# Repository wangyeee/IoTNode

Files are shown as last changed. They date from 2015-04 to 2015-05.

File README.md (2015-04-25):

# IoTNode

My IoT implementation with STM32F0 and nRF24L01.

## Compile and run

1. Install [GNU Tools for ARM Embedded Processors](https://launchpad.net/gcc-arm-embedded). And execute `make` to compile the code.
2. For Linux and OS X, clone this [repo](https://github.com/texane/stlink), follow the instructions on that page and install st-util to your system.
3. Execute `make flash` to download the binray to a STM32F0 target via ST Link.

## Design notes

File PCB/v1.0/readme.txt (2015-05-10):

The first version of hardware, tested and working under normal circumstances. But it’s not carefully designed as I’m not a experienced hardware developer.

Reference documents:
AN4080: Getting started with STM32F0x1/x2/x8 hardware development.
RM0360: STM32F030x4/6/8/C and STM32F070x6/B advanced ARM-based 32-bit MCUs Reference manual.
STM32F072B Discovery board schematics.

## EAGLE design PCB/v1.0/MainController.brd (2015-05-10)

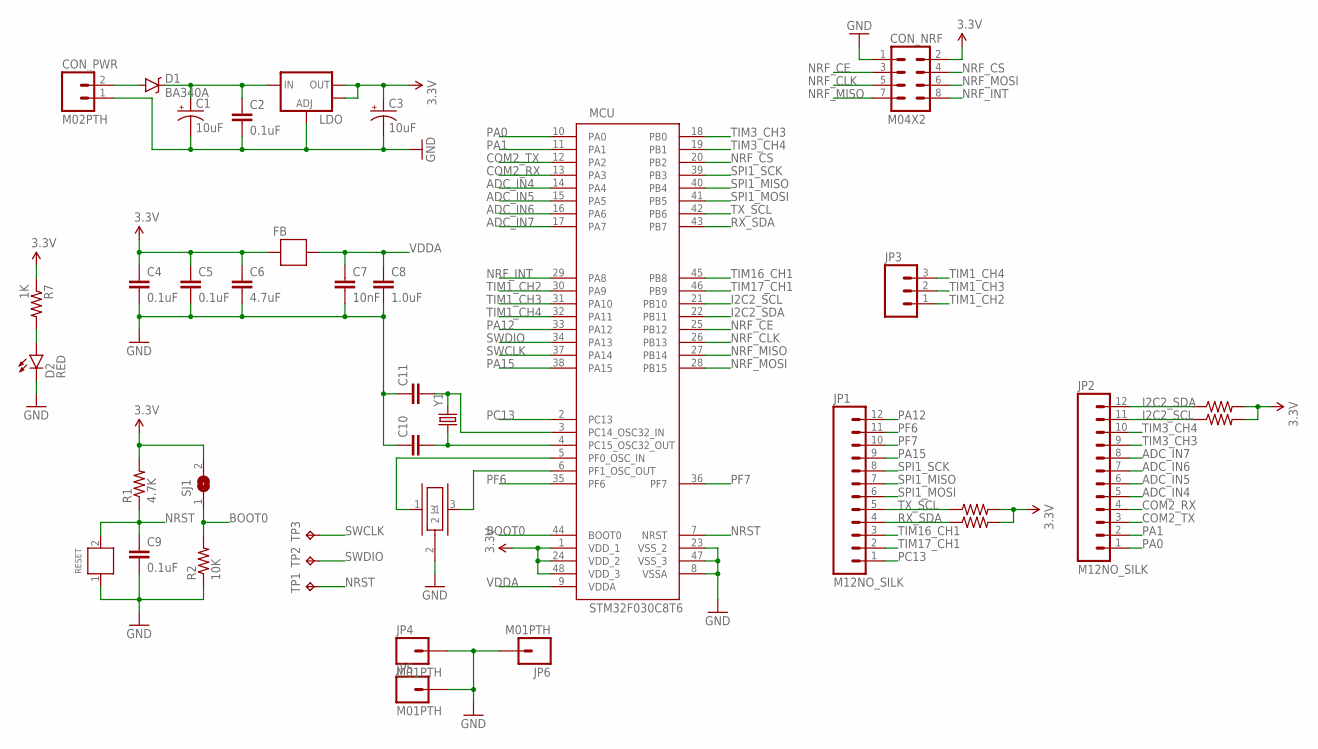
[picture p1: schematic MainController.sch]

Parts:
C1, C3: 10uF; EIA3216
C2, C4, C5, C9: 0.1uF; 0603-CAP
C6: 4.7uF; 0603-CAP
C7: 10nF; 0603-CAP
C8: 1.0uF; 0603-CAP
C10, C11: CAP0603-CAP; 0603-CAP
CON_NRF: M04X2; 2X4
CON_PWR: M02PTH; 1X02
D1: BA340A; SMA-DIODE
D2: RED; LED-0603
FB: FBFB0805; 0805W
JP1, JP2: M12NO_SILK; 1X12_NO_SILK
JP3: M031X03_NO_SILK; 1X03_NO_SILK
JP4, JP5, JP6: M01PTH; 1X01
LDO: V_REG_LM1117SOT223; SOT223
MCU: STM32F030C8T6; TQFP48
OSC: CSTCE8M00G52-R0; CSTCE_M_G
R1: 4.7K; 0603-RES
R2, R3, R4, R5, R6: 10K; 0603-RES
R7: 1K; 0603-RES
RESET: SWITCH_SMD; SWITCH3X6_SMD
SJ1: SJ
TP1, TP2, TP3: TPB1,27; B1,27
Y1: CRYSTALTC38H; TC38H

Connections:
3.3V: C3.A (+), C4.1, C5.1, C6.1, CON_NRF.2, FB.2, LDO.2 (OUT), LDO.4 (OUT), MCU.1 (VDD_1), MCU.24 (VDD_2), MCU.48 (VDD_3), R1.2, R3.2, R4.2, R5.2, R6.2, R7.1, SJ1.2
ADC_IN4: JP2.5, MCU.14 (PA4)
ADC_IN5: JP2.6, MCU.15 (PA5)
ADC_IN6: JP2.7, MCU.16 (PA6)
ADC_IN7: JP2.8, MCU.17 (PA7)
BOOT0: MCU.44 (BOOT0), R2.2, SJ1.1
COM2_RX: JP2.4, MCU.13 (PA3)
COM2_TX: JP2.3, MCU.12 (PA2)
GND: C1.C (-), C2.2, C3.C (-), C4.2, C5.2, C6.2, C7.2, C8.2, C9.2, C10.1, C11.1, CON_NRF.1, CON_PWR.1, D2.C, JP4.1, JP5.1, JP6.1, LDO.1 (ADJ), MCU.8 (VSSA), MCU.23 (VSS_2), MCU.47 (VSS_3), OSC.2, R2.1, RESET.1
I2C2_SCL: JP2.11, MCU.21 (PB10), R5.1
I2C2_SDA: JP2.12, MCU.22 (PB11), R6.1
unnamed: MCU.5 (PF0_OSC_IN), OSC.1
unnamed: MCU.6 (PF1_OSC_OUT), OSC.3
unnamed: C1.A (+), C2.1, D1.C, LDO.3 (IN)
unnamed: C10.2, MCU.4 (PC15_OSC32_OUT), Y1.1
unnamed: C11.2, MCU.3 (PC14_OSC32_IN), Y1.2
unnamed: CON_PWR.2, D1.A
unnamed: D2.A, R7.2
NRF_CE: CON_NRF.3, MCU.25 (PB12)
NRF_CLK: CON_NRF.5, MCU.26 (PB13)
NRF_CS: CON_NRF.4, MCU.20 (PB2)
NRF_INT: CON_NRF.8, MCU.29 (PA8)
NRF_MISO: CON_NRF.7, MCU.27 (PB14)
NRF_MOSI: CON_NRF.6, MCU.28 (PB15)
NRST: C9.1, MCU.7 (NRST), R1.1, RESET.2, TP1.TP
PA0: JP2.1, MCU.10 (PA0)
PA1: JP2.2, MCU.11 (PA1)
PA12: JP1.12, MCU.33 (PA12)
PA15: JP1.9, MCU.38 (PA15)
PC13: JP1.1, MCU.2 (PC13)
PF6: JP1.11, MCU.35 (PF6)
PF7: JP1.10, MCU.36 (PF7)
RX_SDA: JP1.4, MCU.43 (PB7), R4.1
SPI1_MISO: JP1.7, MCU.40 (PB4)
SPI1_MOSI: JP1.6, MCU.41 (PB5)
SPI1_SCK: JP1.8, MCU.39 (PB3)
SWCLK: MCU.37 (PA14), TP3.TP
SWDIO: MCU.34 (PA13), TP2.TP
TIM1_CH2: JP3.1, MCU.30 (PA9)
TIM1_CH3: JP3.2, MCU.31 (PA10)
TIM1_CH4: JP3.3, MCU.32 (PA11)
TIM3_CH3: JP2.9, MCU.18 (PB0)
TIM3_CH4: JP2.10, MCU.19 (PB1)
TIM16_CH1: JP1.3, MCU.45 (PB8)
TIM17_CH1: JP1.2, MCU.46 (PB9)
TX_SCL: JP1.5, MCU.42 (PB6), R3.1
VDDA: C7.1, C8.1, FB.1, MCU.9 (VDDA)

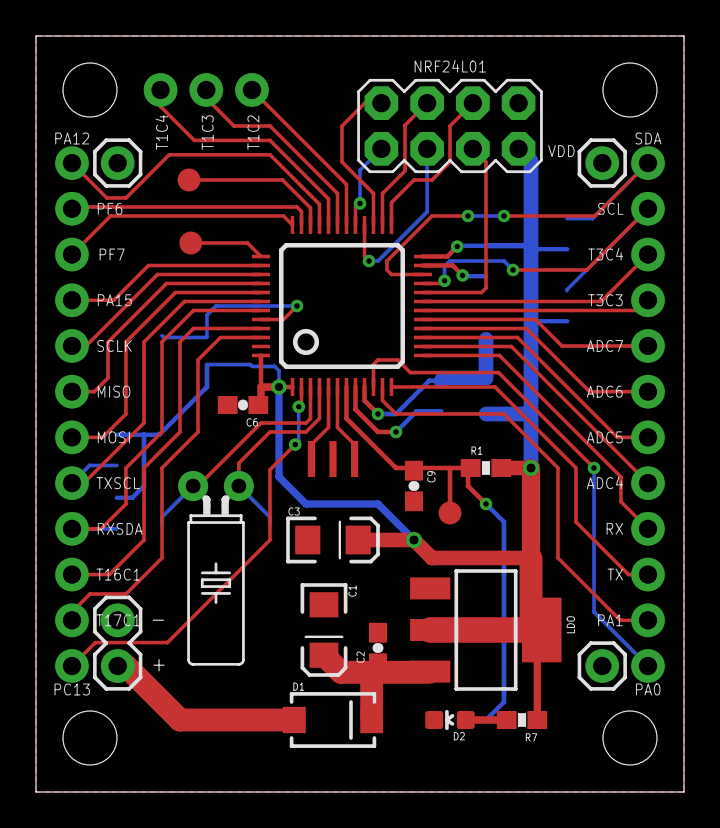
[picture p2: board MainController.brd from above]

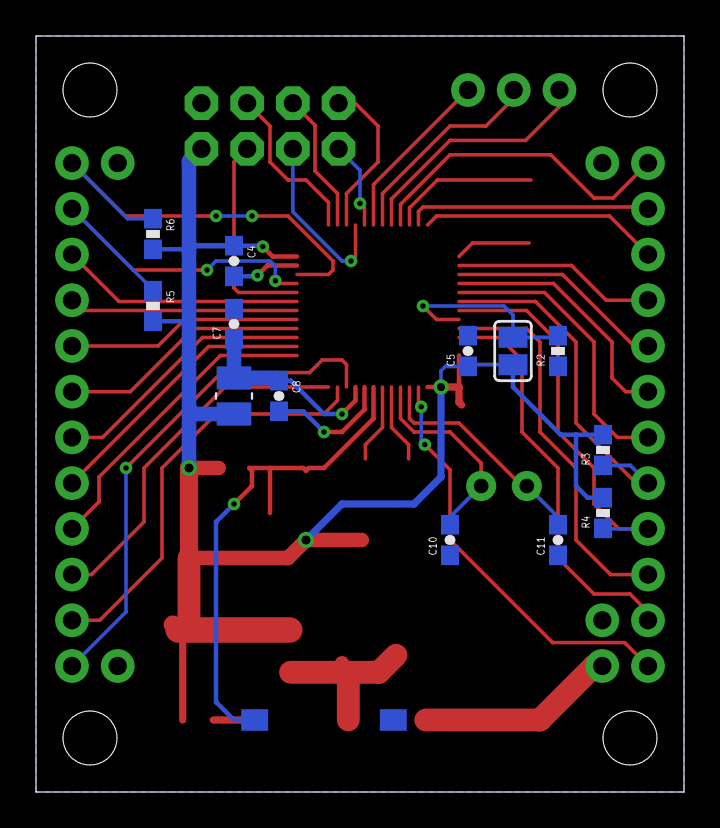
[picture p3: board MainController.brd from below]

Board: 2 copper layers, 36.0 x 42.0 mm, 38 parts (14 on the bottom side), 47 nets.

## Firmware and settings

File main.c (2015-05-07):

#include "stm32f0xx.h"
#include "utility.h"
#include "spi.h"
#include "nrf24l01.h"
#include "node_config.h"
#include "gpio.h"
#include "adc.h"
#include "pwm.h"
#include "iot_cfg.h"
#include "SPI2Serial.h"
#include "NodeLink.h"
#include "SwitchControl.h"

void spi2serial_main(void) {
    uint8_t status;
    /* TODO load listening address from flash. */
    uint8_t thisAddr[5]= {97, 83, 22, 222, 121};

    init_stdio_USART2();
    init_delay();

    SPI2_Init();

    delay_ms(10);

    nrf24l01Init();

    delay_ms(100);
    status = nRF24_Check();

    if (status == 1) {
        for (;;);
    }
    nrfSetRxMode(92, 5, thisAddr);
    init_node_link();

    for (;;) {
        status = SPI2Serial_Loop();
        if (status) {
            nrfSetRxMode(92, 5, thisAddr);
        }
    }
}

void node_main(void) {
    uint8_t status;
    /* TODO load listening address from flash. */
    uint8_t thisAddr[5]= {97, 89, 64, 222, 121};

    init_stdio_USART2();
    init_delay();

    SPI2_Init();

    delay_ms(10);

    nrf24l01Init();

    delay_ms(100);
    status = nRF24_Check();

    if (status == 1) {
        for (;;);
    }
    printf("nRF check OK!\n");

    nrfSetRxMode(92, 5, thisAddr);
    init_node_link();
    printf("init_node_link OK!\n");
    nRF_Task_Init();
    /* From now on, controls and sensors can be initialized. */
    init_switches();
    printf("init_switches OK!\n");

    for (;;) {
        nRF_Task_Loop();
        delay_ms(1);
    }
}

__attribute__((noreturn))
int main(void) {
#ifndef ENABLE_SPI2SERIAL
    node_main();
#else
    spi2serial_main();
#endif
    for (;;);
}

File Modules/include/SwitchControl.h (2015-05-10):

#ifndef _SWITCHCONTROL_H_
#define _SWITCHCONTROL_H_

#ifdef __cplusplus
extern "C" {
#endif

#ifdef STM32F0XX
#include "stm32f0xx.h"
#include "gpio.h"
#endif

#include "NodeLink.h"

#define NUMBER_OF_SWITCHES 7

/*
 * id  GPIO
 *  0  PA0
 *  1  PA1
 *  2  PA12
 *  3  PA15
 *  4  PC13
 *  5  PF6
 *  6  PF7
 */
typedef struct _switch_t {
    uint8_t id : 4;
    uint8_t status : 2;
    uint8_t enabled : 2;
    uint8_t (*pack)(struct _switch_t* sw, uint8_t* buf, uint8_t len);
    uint8_t (*unpack)(struct _switch_t* sw, uint8_t* buf, uint8_t len);
#ifndef STM32F0XX
/* Compile for server */
    node_t node;
#endif
} __attribute__ ((__packed__)) switch_t;

#define SWITCH_SIZE sizeof(switch_t)

typedef enum {
    OFF = 0,
    ON
} switch_status;

#ifdef STM32F0XX

void init_switches(void);
uint8_t switch_message_listener(node_t from, uint8_t* msg, uint8_t len);

#endif /* STM32F0XX */

/**
 * 0 1 2 3 | 4 5     | 6 7
 * id      | enabled | status
 */
static uint8_t switch_pack(struct _switch_t* sw, uint8_t* buf, uint8_t len) {
    if (len > 0) {
        buf[0] = (uint8_t) ((sw->id << 4) | (sw->enabled << 2) | sw->status);
        return 1;
    }
    return 0;
}

static uint8_t switch_unpack(struct _switch_t* sw, uint8_t* buf, uint8_t len) {
    if (len > 0) {
        sw->id = (buf[0] & 0b11110000) >> 4;
        sw->enabled = ((buf[0] & 0b00001100) >> 2) ? ENABLED : DISABLED;
        sw->status = (buf[0] & 0b00000011) ? ON : OFF;
        return 1;
    }
    return 0;
}

static void init_switch_type(switch_t* sw) {
    sw->enabled = DISABLED;
    sw->id = 0;
    sw->status = OFF;
    sw->pack = switch_pack;
    sw->unpack = switch_unpack;
}

#ifdef __cplusplus
}
#endif
#endif /* _SWITCHCONTROL_H_ */

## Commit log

2015-04-01 Add PWM output support.
2015-04-12 Add ILI9163C LCD driver support.
2015-04-18 Tested nRF24L01 driver.
2015-04-25 Add build configuration file. Tested SPI2Serial bridge. Added switch test code.
2015-04-27 Add switch control module.
2015-04-28 Fixed careless macro definition error.
    [SwitchControl.h]
2015-05-07 Refactoring switch control code with NodeLink. 1. Adding pack/unpack function for control struct to deal with bit order issue. 2. Adding test cases to test switch control without a PHP application se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
    [SwitchControl.h, main.c]
2015-05-10 Modify serial SPI bridge for consistence issue.
    [SPI2Serial.c, SwitchControl.h]
2015-05-10 Add 1.0 version of PCB desgin.
    [MainController.brd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]

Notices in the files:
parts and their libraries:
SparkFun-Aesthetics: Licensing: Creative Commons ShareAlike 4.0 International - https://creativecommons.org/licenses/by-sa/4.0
